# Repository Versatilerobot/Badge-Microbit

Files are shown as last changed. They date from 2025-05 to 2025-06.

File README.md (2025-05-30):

# Badge-Microbit
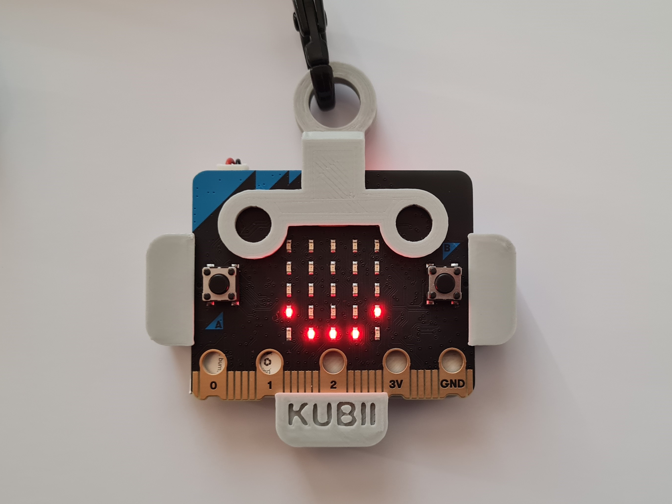
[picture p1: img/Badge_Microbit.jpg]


Ce badge animé en forme de tête de robot stylisée est prévu pour être porté avec une longe de tour de cou. <br />
Il supporte une carte Micro:bit BBC V2.21 et une batterie rechargeable Lipo 250mAh 3,7V. <br />
Les animations sont les suivantes : <br />
-	« Scrolling du nom CALIBAN» Association Française de robotique amateur <br />
https://www.facebook.com/AssoCaliban;
-	« Smile » du robot avec mélodie (appuie sur Bouton poussoir « A »)
-	« Cœur » qui bat avec bruitage (appuie sur Bouton poussoir « B »)<br />

La mélodie ou le bruitage peuvent êtres désactivés pour chaque animation par un appuie sur l’autre bouton (Ex : Appuie sur « B » si animation encours est « Smile », ou Appuie sur « A » si animation encours est « Coeur ») <br />
La carte peut être mise en mode d'économie d'énergie en maintenant enfoncée le bouton de Reset au dos. Lorsque la LED d'alimentation s'éteint, relâchez le bouton pour mettre votre micro:bit en mode d'économie d'énergie. <br />
Un appuie court sur le même bouton redémarre la carte. <br />

Dans ce dossier vous trouverez toutes les informations pour le construire et le programmer :<br />
-	Les fichiers STL pour l’impression avec un remplissage à 30% sans supports
-	Un exemple de code en microPython Mu https://codewith.mu/
-	Une liste du matériel et une suggestion de liens pour se le procurer <br />
  Nota: La recharge de la batterie doit être réalisée à part.

Une démo au lien suivant: https://youtu.be/-zeMkWJXh7k <br />
Une vidéo de l'assemblage: https://youtu.be/kdMkO-jAXIA

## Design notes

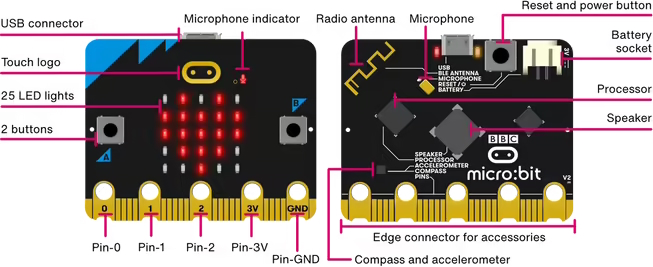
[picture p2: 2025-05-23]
img/BBC-microbit-V2.21.jpg

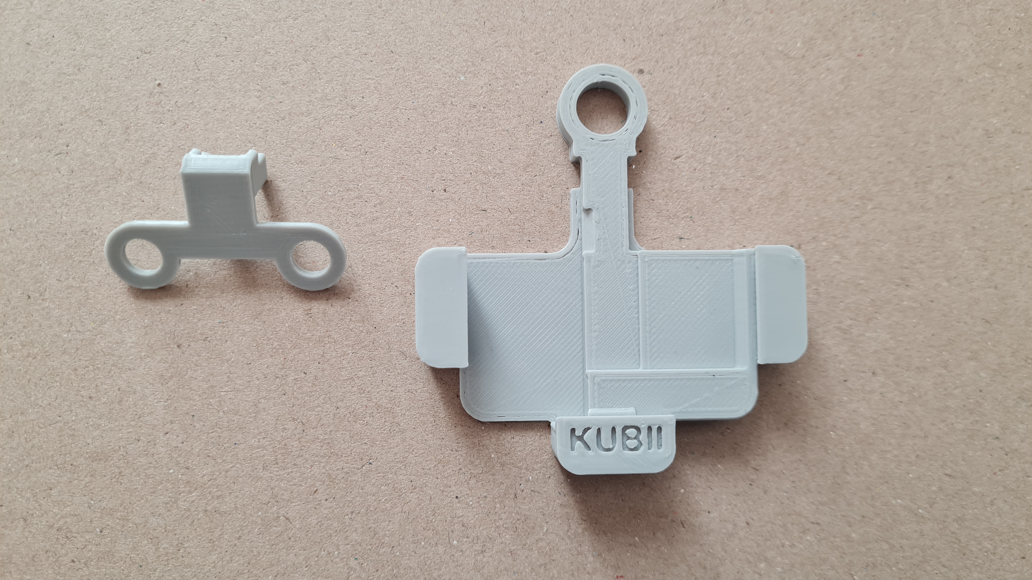
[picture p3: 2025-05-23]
img/Front_&_Back.jpg

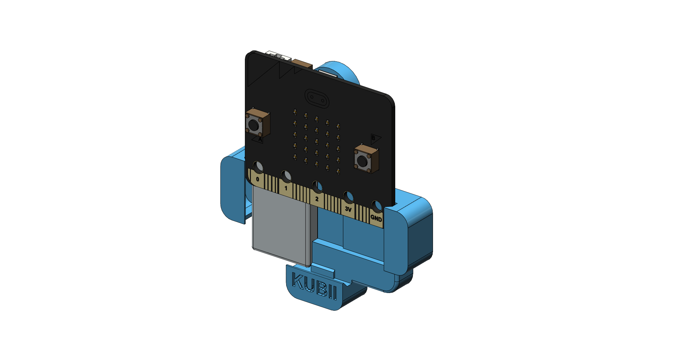
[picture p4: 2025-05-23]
img/Slide the MicroBit in slit.png

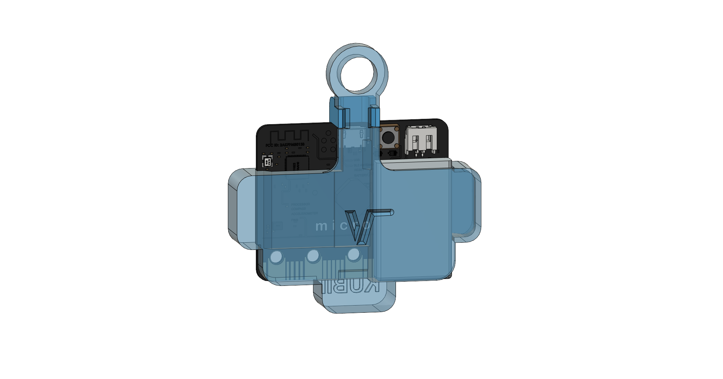
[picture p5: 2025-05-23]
img/Battery pack.png

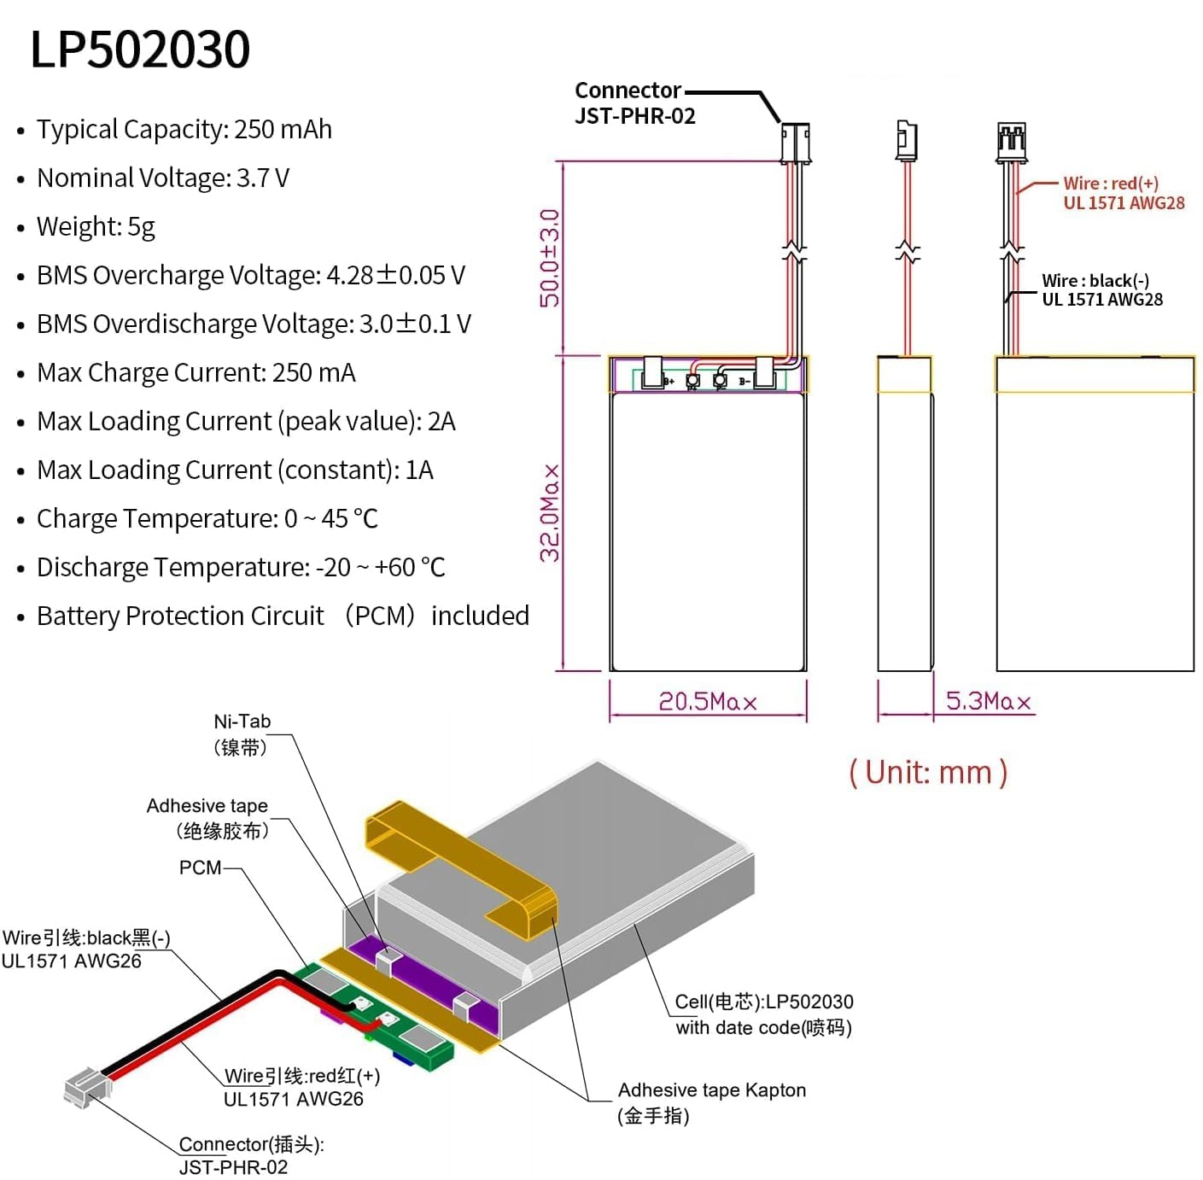
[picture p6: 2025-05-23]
img/3.7V 502030 Battery 250mAh Lipo with JST Connector.jpg

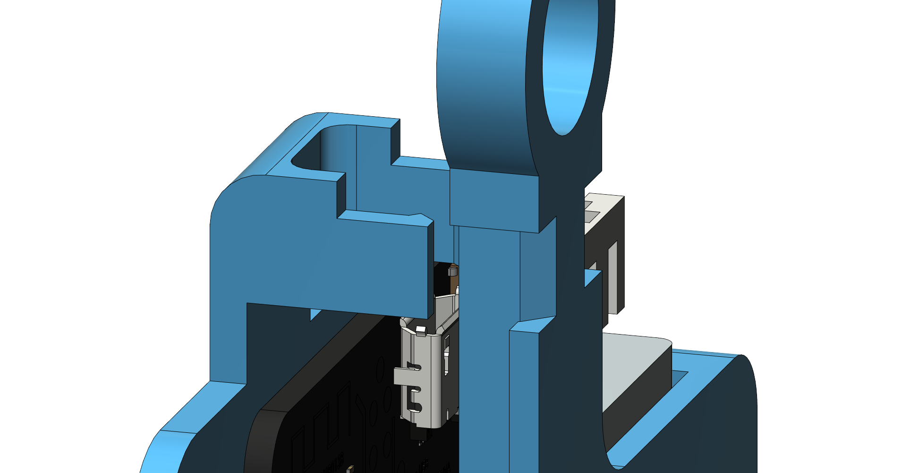
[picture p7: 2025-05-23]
img/Clip and lock the front part.png

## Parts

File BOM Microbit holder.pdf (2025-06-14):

GF | BOM Microbit holder.xlsx | 14/06/2025

Electronic
componants

Price Per
Parcell €

Quantity
per Parcell

Quantity
needed

Price per
Unit €

Price per
Kit €
| | | | | | Notes | Examples
BBC-microbit-V2.21 | 19,34 | 1 | 1 | 19,34 | 19,34 | Carte Micro:bit BBC V2 avec speaker incorporé | Carte Micro:bit BBC V2 (https://www.kubii.com/fr/cartes-micro-controleurs/3091-carte-microbit-bbc-v2-5051259252585.html)
Longue pour porte-badge | 8,19 | 1 | 1 | 8,19 | 8,19 | Longe pour Porte-badge | Longe porte-badge (https://www.amazon.fr/PATIKIL-Lani%C3%A8res-R%C3%A9glable-Porte-cl%C3%A9s-Porte-badges/dp/B0C4TNR99X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)
Battery Lipo 250mAh 3,7V | 8,28 | 1 | 1 | 8,28 | 8,28 | Batterie 502030 - 250mAh Lipo avec connecteur JST-PHR-02 32x20,5x5,3 ! Choisir la bonne polarité ! | Battery Lipo 250mAh with JST Connector. (https://www.amazon.fr/EEMB-polym%C3%A8re-Batterie-Rechargeable-connecteur/dp/B0B7R8CS2C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)
| | | | | 35,81
3D parts raw material | Price
| €/Kg | Weight
| | g | Quantity
| | | needed | Price Per
| | | | Unit € | Price per
| | | | | kit € | Notes
| | | | | | A titre indicatif seulement - Imprimante Flsun FQQ Pro | Examples
back.stl | 18 | 11 | 1 | 0,20 | 0,20 | 3,79m PLA gris 0h50 min | Filament PLA 1.75mm 1kg (https://www.kubii.com/fr/consommables/4318-2052-filament-pla-175mm-1kg-3272496318540.html)
front.stl | 18 | 1 | 1 | 0,02 | 0,02 | 0,45m PLA gris 0h08 min | Filament PLA 1.75mm 1kg (https://www.kubii.com/fr/consommables/4318-2052-filament-pla-175mm-1kg-3272496318540.html)
| | 12 | 2 | | 0,22
3D parts printing electricity | Price
| €/kWh | 3D printer
| | Power W | Quantity
| | | needed h | 3D printer
| | | | price kWh | Price per
| | | | | kit € | Notes
| | | | | | A titre indicatif seulement - Imprimante Flsun FQQ Pro
| 0,21 | 150 | 1 | 0,03 | 0,03
Total | | | | | 36,06
Option USB charger | Price Per
| Parcell € | Quantity
| | per Parcell | Quantity
| | | needed | Price per
| | | | Unit € | Price per
| | | | | Kit € | Notes | Examples
Micro Lipo - USB Charger | 8,29 | 1 | 1 | 8,29 | 8,29 | Micro Lipo - USB Charger - 5V to 3,7V | Micro Lipo - USB Charger (https://www.amazon.fr/Adafruit-Micro-Lipo-charger-ADA1304/dp/B00OKJFEQ2)

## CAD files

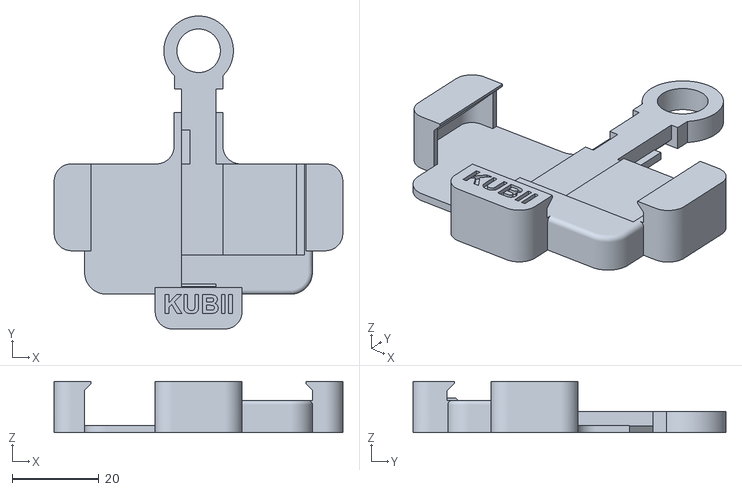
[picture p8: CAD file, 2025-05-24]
3D_STL/back.stl
66.4 x 72.0 x 11.8

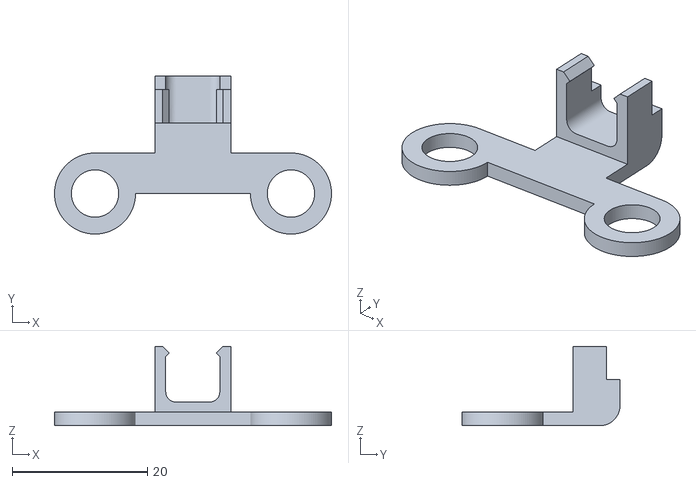
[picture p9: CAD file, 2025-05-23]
3D_STL/front.stl
41.0 x 23.4 x 11.8

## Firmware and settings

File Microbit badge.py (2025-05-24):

from microbit import *

import audio
import utime
import music

try:
    speaker.on()
except NameError:
    speaker = None

try:
    from microbit import Sound
except ImportError:
    Sound = None

start = utime.ticks_ms()

while True:

    display.scroll('CALIBAN', delay=175, wait=False, loop=False)
    while utime.ticks_ms() < start + 7000 :
        if button_a.was_pressed():
            while not button_a.was_pressed():
                display.show(Image.SMILE)
                if button_b.was_pressed() is True :
                    speaker.off()
                audio.play(Sound.GIGGLE, wait=False)
                sleep(1000)
                display.show(Image.SQUARE_SMALL)
                sleep(1000)
            break
        if button_b.was_pressed():
            while not button_b.was_pressed():
                display.show(Image.HEART_SMALL)
                if button_a.was_pressed() is True :
                    speaker.off()
                music.pitch(880, 6)
                sleep(500)
                display.show(Image.HEART)
                music.pitch(880, 6)
                sleep(500)
                display.clear()
                sleep(1000)
            break
        pass
    speaker.on()
    start = utime.ticks_ms()
